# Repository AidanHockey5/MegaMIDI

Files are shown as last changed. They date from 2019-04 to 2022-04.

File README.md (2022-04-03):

# Mega MIDI

https://www.aidanlawrence.com/mega-midi-a-playable-version-of-my-hardware-sega-genesis-synth/

[Instruction Manual](https://www.aidanlawrence.com/wp-content/uploads/2019/07/MegaMidi5Manual.pdf)

[Store Link](https://www.aidanlawrence.com/product/mega-midi-5/)

This project contains the source material for the Mega MIDI, a MIDI-controlled Sega Genesis/Megadrive Synthesizer that uses the genuine sound chips from the console itself. The primary FM sound source is the Yamaha YM2612, but I have also included the SN76489 PSG which was also present on the Sega Genesis. This synthesizer does not use emulated sound - it's the real deal. Therefore, you are limited to the limitations of the actual hardware, which I will explain in more detail down below.

# Why Not Just Emulate?
You'd be hard-pressed to find an emulated YM2612 core that sounds exactly like the real YM2612. There are some that get close, but nothing compares to the real thing. Yamaha's FM synthesis is pretty tricky to emulate in the first place, but the YM2612's signature gritty DAC is mostly to blame for the lack of truly accurate emulation. Not with The Mega MIDI though. Since you are using the real YM2612 and SN76489 ICs, you can experience playing the Sega Genesis as a musical instrument with the true fidelity and accuracy as the real thing.

# Play Any Instrument from Any Genesis Video Game Music
The Mega MIDI reads in ".opm" files. OPM files were originally designed for the VOPM virtual synthesizer. The OPM format stores the register data for FM patches that you can use to easily program your YM2612 with. FM synthesis is very complicated, so while you still have the option to create your own FM patches, it would be way easier to just directly take the FM voice patches from the games themselves and use them on your Mega MIDI. With the Mega MIDI, you can, in fact, DIRECTLY play FM patches from any Sega Genesis game's music. These aren't "sound-alike" patches either, they are the actual identical patches lifted directly from the game's source. Do you like ThunderForce's Guitar patch in the track Metal Squad? Play it. Want to try your hand playing Chemical Plant Zone's bass patch? Go for it. Any track. Any instrument. Instantly.

# Where Do I find OPM files?
There are two ways:

1) There is a massive pack of ripped OPM files ready to go that spans almost the entire Genesis library. You can find just about anything in this collection. [Click here to download it.](https://www.aidanlawrence.com/wp-content/uploads/2019/03/2612org-OPMs.zip)
One thing to note: This is a REALLY big collection of files. I don't recommend putting them ALL on your SD card at once as load times will begin to suffer. 

2) You can convert any OPN2(YM2612) .VGM file to an OPM patch using the vgm2opm tool courtesy of [Shiru](https://shiru.untergrund.net) and https://github.com/vampirefrog/fmtools

I have included a windows-compiled binary of vgm2opm within the [tools](https://github.com/AidanHockey5/MegaMIDI/tree/master/tools) directory of this repository along with a batch-file to automatically execute the tool. To use this tool, simply place your desired .vgm/vgz files within the VGM_IN folder, double-click the CONVERT_VGM_OPM.bat file, then retrieve your OPM patch files in the OPM_OUT folder.

# USB MIDI and Traditional DIN MIDI Compatible
Want to control The Mega MIDI through software like Ableton, FL Studio, or any other DAW? You can! The Mega MIDI will show up like any other MIDI-compatible instrument and is able to receive native USB MIDI commands without any sort of serial bridge. 
Prefer old-school traditional 5-pin DIN MIDI instead? Go for it! Bust out that classic MIDI controller and plug it in with zero additional setup required.

# Crystal-Clear Amplification 
Now featuring a modified version of the Mega Amp Mod! Beautifully clear amplification for both the YM3438 and the YM2612!

# 7 "Favorite" Buttons to Quickly Swap Between Your Favorite Patches
While you do have access to every .opm file on your Mega MIDI's SD card, sometimes you'll find the *perfect* patch that you'll want to keep for easy-access later. Simply hold-down one of the seven "favorite" buttons at the bottom of the board and your currently loaded patch will be saved into EEPROM. Because favorite patches are saved to EEPROM, you can access them instantaneously without any load times. Perfect for swapping patches on-the-fly!

# Real Hardware, Real Limitations
Because you are working with the real sound chips, you are also working under their real limitations. The YM2612 is a six-channel sound chip, meaning you can play six individual notes at once. The SN76489 PSG is a 3-channel square-wave-only (excluding noise) chip. In total, you can have nine total channels of sound if you're playing both the PSG and the YM2612 at the same time.

While some might find this a bit limiting, others may enjoy the challenge of getting as much sound as they possibly can within the limits of the genuine hardware. Countless other video game music composers did it, now you can experience it too!

# Open-source
All of my source material has been made open-source. Want to build your own Mega MIDI from scratch? Go for it! Have some modifications in mind? I'd love to see them! If you do decide your own version, please credit me: Aidan Lawrence and refer back to this original repository. Please do not resell this project.

# Tools
The firmware for this project was developed in [Visual Studio Code](https://code.visualstudio.com/) with the [PlatformIO extention.](https://docs.platformio.org/en/latest/ide/vscode.html) I used the Teensyduino (ArduinoTeensy) toolchain.

The schematics/PCB files were made with [KiCAD.](http://kicad.org/) Specifically, version 5.0.2.

Precompiled firmware HEX files can be found here:
https://github.com/AidanHockey5/MegaMIDI/releases/

Here is the schematic:
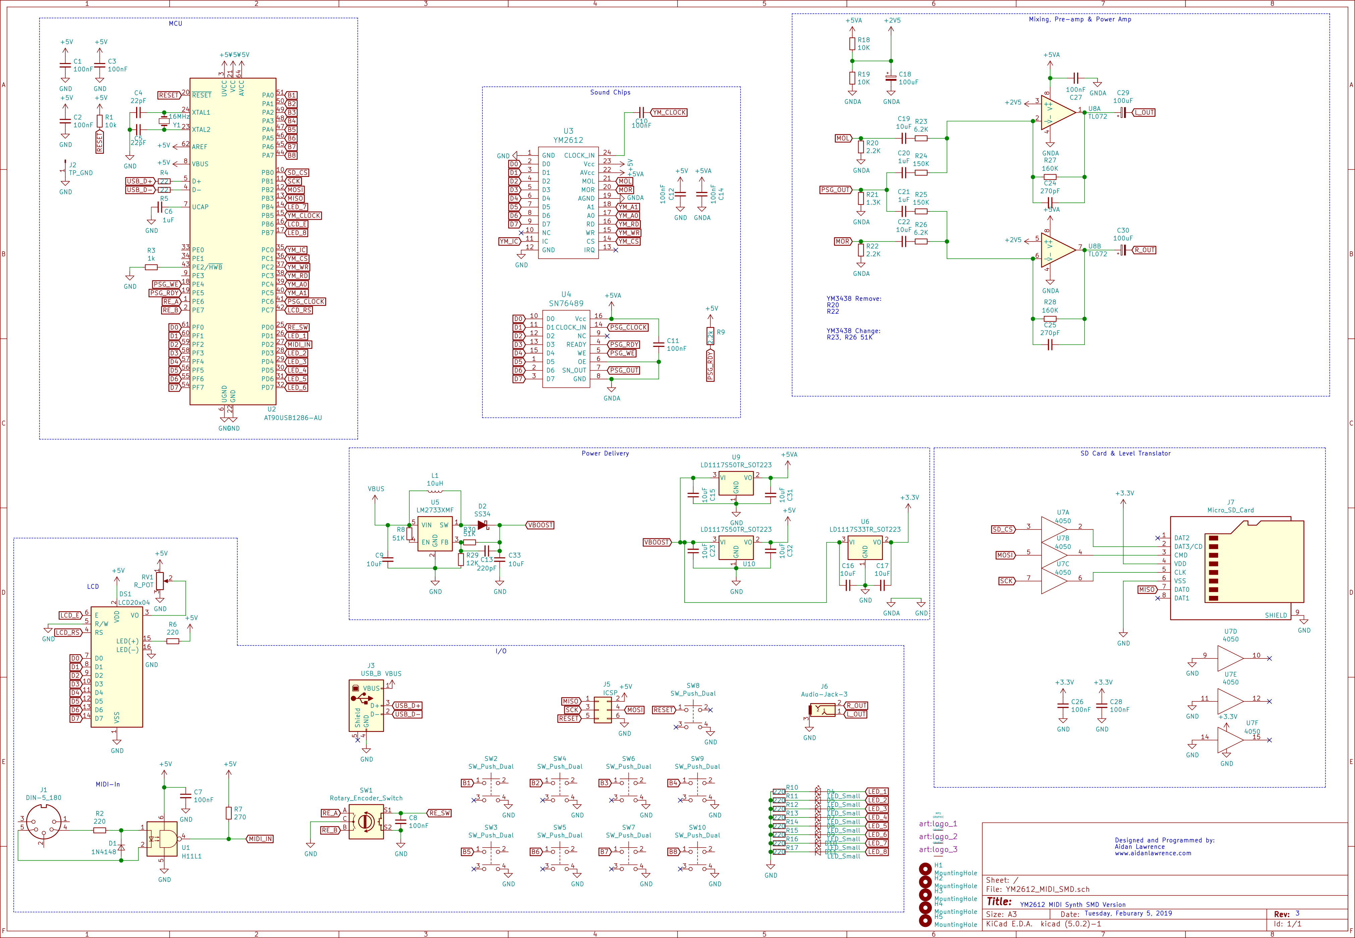
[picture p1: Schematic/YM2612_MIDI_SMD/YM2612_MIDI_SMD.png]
Here is the schematic so far


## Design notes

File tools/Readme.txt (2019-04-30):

Here are a few tools to help you operate the YM2612 MIDI device
You need to make sure you have installed the Teensyduino files from PJRC!
https://www.pjrc.com/teensy/td_download.html

SERIAL CONNECTIONS
--------------------------------------------------
You can use the SERIAL_CONNECT.bat file to open up a virtual serial port in order to send commands to the device.

Inside of the SERIAL_CONNECT.bat file reads:
::This batch file will open the teensy_gateway program and a putty serial window
::Keep the black teensy_gateway window open and work inside of the putty window
::If everything is working, you should see the text "teensy_gateway" inside of the putty window.
::Use the putty window as if you were using the Arduino Serial console.
::Type-in your commands, then hit enter to execute them

CONVERT VGM FILES TO OPM FILES
--------------------------------------------------
You can use this tool to extract the voices out of VGM files and place them in an .OPM file to use with your YM2612 MIDI device
The VGM files MUST contain YM2612/YM3438 instrument data

Place your VGM/VGZ files in the VGM_IN and run the "CONVERT_VGM_OPM.bat" file.
After the program runs, go into the OPM_OUT folder and you should see your new .OPM files.
Add these .OPM files to the SD card of your YM2612 MIDI project.

PROGRAMMING
--------------------------------------------------
While you can easily use something like an ATMEL ICE programmer and Atmel Studio, you can also use a plain ol' Arduino board to act
as a programmer.

You can use the ArduinoISP sketch from the Arduino IDE to turn any standard Arduno Uno/Nano/Mega into a programmer.
It is reccomended that you change the ArduinoISP programmer speed to  #define BAUDRATE	1000000 (line 144), but the default
setting of 19200 works too, though it is very slow.

Pin connections:
The Mega MIDI 6-pin programming connector looks like this:

      MISO °. . 5V 
      SCK   . . MOSI
      RST   . . GND

Arduino | Mega MIDI programming header
GND     | GND
10      | RST
11      | MOSI
12      | MISO
13      | SCK

You do not need to connect 5V.

Run FLASH.bat and choose your COM port number and programming speed.

The SD card will not read properly after being programmed with an ISP device. Remove the SD card, reinsert the card, then press the RESET button on the Mega MIDI board.

Default AVRDUDE command is:
avrdude -c arduino -p usb1286 -P COM16 -b 19200 -U flash:w:"LOCATION_OF_YOUR_PROJECT_FOLDER\.pioenvs\teensy20pp\firmware.hex":a -U lfuse:w:0x5E:m -U hfuse:w:0xDF:m -U efuse:w:0xF3:m

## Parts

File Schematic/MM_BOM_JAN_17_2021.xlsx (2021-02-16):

Quantity | Manufacture Part Number | Manufacturer(optional) | Description(optional) | LCSC Part Number(optional) | Package(optional) | Customer Part Number(optional)
3 | VDV107M035S0ANE04K |  | 100uF | C190423
2 | 0603N220J500CT |  | 22pF | C302059
1 | CL10B221KB8NNNC |  | 220pF | C1603
12 | TCC0805X7R104K500DT |  | 100nF | C282732
3 | CC0805KKX5R6BB105 |  | 1uF | C408907
2 | 0805B271K500CT |  | 270pF | C237202
10 | CL31B106KAHNNNE |  | 10uF | C14860
10 | RMC08052201%N |  | 220R | C325771
3 | 0805W8F1002T5E |  | 10K | C17414
3 | 0805W8F2201T5E |  | 2.2K | C17520
2 | 0805W8F220JT5E |  | 22R | C17561
2 | 0805W8F5102T5E |  | 51K | C17737
2 | 0805W8F6201T5E |  | 6.2K | C17767
2 | WR08X1583FTL |  | 150K | C170801
2 | 0805W8F1603T5E |  | 160K | C17485
1 | WR08X102JTL |  | 1K | C384174
1 | RTT052700FTP |  | 270R | C104166
1 | RK73B2ATTD132J |  | 1.3K | C316774
1 | AECR0805F12K0K9 |  | 12K | C352272
1 | SWPA4018S100MT |  | 10uH | C83442
1 | SS12 |  | SCHOTTKY | C2479
1 | 1N4148W |  | 1N4148 | C84367
8 | TJ-S2012SW8TGLC2R-A5 |  | LED RED | C192318
1 | H11L1SR2M |  | OPTOISOLATOR | C20082
1 | HEF4050BT,653 |  | 4050 BUFFER | C118326
1 | LM833DT |  | OPAMP | C127074
2 | LD1117-5.0 |  | REGULATOR 5V | C347230
1 | LD1117-3.3 |  | REGULATOR 3.3V | C347229
1 | X49SM16MSD2SC |  | 16MHZ CRYSTAL | C12676
1 | 3362P-1-103 |  | POT 10K | C118956
9 | TS-1002-06026 |  | TACT SWITCH | C455093
1 | C124384 |  | PIN HEADER | C124384
1 | DS1009-24AT1WX-0A2 |  | SOCKET DIP24 | C72120
1 | C146580 |  | SOCKET DIP16 | C146580
1 | TF-15x15 |  | SD SOCKET | C111196
1 | LM2733XMFX/NOPB |  | LM2733 | C80169
1 | PJ-307N5 |  | AUDIO JACK | C692542
1 | C46392 |  | USB-B | C46392

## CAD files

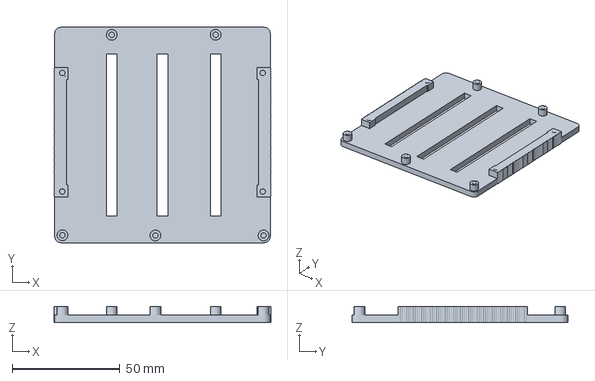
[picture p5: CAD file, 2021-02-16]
3D/Mega_MIDI_Bottom_Plate.3mf
100.7 x 100.0 x 7.55 mm

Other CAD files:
3D/Mega_MIDI_Bottom_Plate.stl

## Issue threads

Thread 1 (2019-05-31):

possible to stick note while receiving midi and pushing encoder

geslotencirkel, 2019-05-31:
when Megamidi is getting midi note data (ch1) it is possible to make notes stick forever.

to reproduce:
-load an opm sound to play.
-send midi notes, preferably fast
-start pushing the encoder to scroll through the onscreen menu

haven't tried this with USB midi, only din.

seems that note off data isn't sent if the encoder is pressed down during a note off event? just a hunch

AidanHockey5, 2019-05-31:
Interesting, I'll give this a look on my unit.
When a new OPM file is loaded in, both of the sound chips are reset. Pushing the encoder will trigger an interrupt routine to update the cursor position and redraw the screen. The interrupt is only triggered on the falling edge of the encoder signal, so I'm curious to see why it's preventing keyOff MIDI commands.

In the meantime if a YM2612 voice is getting stuck on you, pressing the LFO button twice will reset the sound chip.

AidanHockey5, 2019-06-01:
I was able to replicate your issue over serial DIN MIDI, but not using a USB MIDI connection. Since serial operations are interrupt-based, I'm pretty sure the following happened:

I think it has to do with the fact that I was redrawing the LCD inside of the interrupt attached to the rotary encoder's button. Redrawing the LCD takes far too long for a well-performing interrupt, so I've just set a flag instead and will now update the LCD inside of the main loop.

I haven't been able to replicate the stuck voice after I implemented this fix, but since it's an intermittent problem (my favorite... ugh) only time will tell if it's truly fixed. For now though, I'll go ahead and close this issue. Feel free to drop by again if the issue persists!

Here is the pre-compiled hex with the changes made: https://github.com/AidanHockey5/MegaMIDI/releases/tag/1.2.4

Closed 2019-06-01.

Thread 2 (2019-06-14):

Fix for oscillating power amplifier (Output static fix)

AidanHockey5, 2019-06-14:
Hello everyone.

I've noticed a really annoying intermittent hardware bug related to the power amplifier. If you've connected power to your Mega MIDI module and have noticed no "FM sound" and just a bunch of static (or other popping noises), feel your power amplifier IC (U8 on the far right side). If it is getting warm, you are likely experiencing an oscillating amplifier.

*The reason for this is as follows:*
1) The LC filter values are off. C31/32 should be 0.68uF, not 68nF. L3/4 need to be 22uH, not 2.2mH. This is an artifact of my Mega Blaster design that boosted treble, but in this case, it causes instability.
2) My routing in that area is less than ideal. I think the inductors are a little too far away.

*Solutions:*
1) Simply unplug the power supply, wait a moment for the power capacitors to drain, then reapply power. Occasionally, this will work.
2) Replace the components. Unfortunately, this is a little involved. I will give a step-by-step down below on how to replace your components.
3) Tap a 100nF capacitor (rated for at least 16V) against U8's pin 19 and 20. This should give the amp a little capacitive kick to drop out of it's oscillation.
4) Permanently apply 100nF ceramic disc capacitors across U8's pin 11/12 and pin 19/20. This is not recommended as you are essentially shorting the power amplifier. This fix is a "band-aid" and will cause the amp and caps to warm up to around 70°C. You can usually stuff the caps within the IC socket then add the amp chip back over-top. Again, this method is not recommended, but is listed since it's one of the easier fixes.

# Replacing the components
In order to access the necessary components, you will need to remove the display and plastic back plate.

1) Begin by unscrewing the four corner screws on the LCD module.
2) Using a heat-gun or soldering iron, quickly heat as many pins as you can (applying lots fresh solder helps!) and apply a firm upwards pressure to lift the display off of it's pins.
3) You will need to use a solder-pump to remove the excess solder blocking off the LCD pin-holes. You can also use a can of air-duster/compressed air to blast the solder out, but show caution as hot solder may fly everywhere.
4) Remove the five back plate screws and the 4 standoffs, then remove the back plate.
5) Locate L3 and L4. Apply heat to both of their pins and pull from the other side to remove.
6) Remove C32 and C31.
7) Replace C32 and C31 with a 0.68uF 0805 capacitor rated for 16V+
* Here are some! https://www.digikey.com/products/en/capacitors/ceramic-capacitors/60?k=0805%200.68uF
8) Replace L3 and L4 with 22uH radial inductors (8.7x11mm)
* Here are some! https://www.digikey.com/product-detail/en/samsung-electro-mechanics/CL21B684JOFNNNE/1276-2976-1-ND/3891062

Ensure that your LCD header pins sticking out of the main board are clear of any excess solder.

9) Screw the back plate back on using the 5 screws, then screw-in the standoffs. Show caution not to snap-off any of the screws or standoffs by over-torquing them or bending them!
10) Align your LCD onto the standoffs and make sure all of the pins are in their correct location.
11) Re-solder the LCD.

All done!

# What now?

Any Mega MIDIs ordered from me after June 13 2019 will already have this fix applied to them.
A future revision to the Mega MIDI is in the works that will optimize the board layout and hopefully provide better A/D separation. The amplifier circuit will also be replaced with a design based on the Mega Amp Mod. This will simplify my BOM and will make it easier to support YM3438s.

Stay tuned, sorry for the inconvenience! Thank you so much for your patience and support.

Closed 2019-07-01.

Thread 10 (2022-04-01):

Change encoder direction

KeenVox, 2022-04-01:
Hi,

is there a way to change the turning direction of the encoder in software? My encoder seems to decrease when I turn in clockwise instead of increase.

Thx in advance!

AidanHockey5, 2022-04-01:
Hello @KeenVox

Ah, no good. I wonder if you have a bad encoder.
Quick question: Does the encoder _always_ operate in reverse?
As in, counter-clockwise increments and clockwise decrements 100% of the time?
Or is it "most of the time clockwise increments, but sometimes it decrements?"

If it's the former, I should be able to come up with a software patch for your unit.
if it's the latter, I'll follow up and we'll see if we can get this repaired!

-Aidan

KeenVox, 2022-04-02:
Hi Aidan,

thank you for your replay. The encoder always operates in reverse. It works totally fine just the wrong way :-D

A software patch would be great. It's a bit irretating in the moment.

Thx again!

Keen

AidanHockey5, 2022-04-03:
Hey there!

So I've worked on a new feature that allows users to invert their encoder direction by holding down their encoder button for one second. [You can read more about it in the firmware patch notes here.](https://github.com/AidanHockey5/MegaMIDI/releases/tag/1.51)

To update your firmware, you'll need an Arduino and just a couple cheap components. [I've created a flashing guide in the instruction manual on page 11](https://www.aidanlawrence.com/wp-content/uploads/2019/07/MegaMidi5Manual.pdf)

You can also find a video guide here https://www.youtube.com/watch?v=DDNO9py8enI

I know that updating the firmware is a little bit involved, but once it's done, you should be able to invert your encoder and have your unit behave in a more intuitive manner.

I apologize for the inconvenience, but I hope this helps out! Feel free to let me know if you have any questions at all or need assistance flashing the firmware.

KeenVox, 2022-04-03:
Hey, thats great! Thank you!

Closed 2022-04-03.

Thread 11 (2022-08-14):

Pitch bend does not center correctly on the SN76489

wik-wav, 2022-08-14:
After adding a midi automation lane and sending any pitch bend change in a DAW (and I presume moving the pitch wheel would cause this as well, but I can't test this as I have no controller) the pitch of the SN76489 moves down by half of the total pitch bend range. In DAWs where there is always a midi lane, the pitch is wrong from the start. This happens on midi channels 2 and 4.

For example if the note C is played, the note 2 semitones below it is A#. Before adding the pitch bend automation the note C is played. After adding PB, the note A# is played with the pitchbend at 0.

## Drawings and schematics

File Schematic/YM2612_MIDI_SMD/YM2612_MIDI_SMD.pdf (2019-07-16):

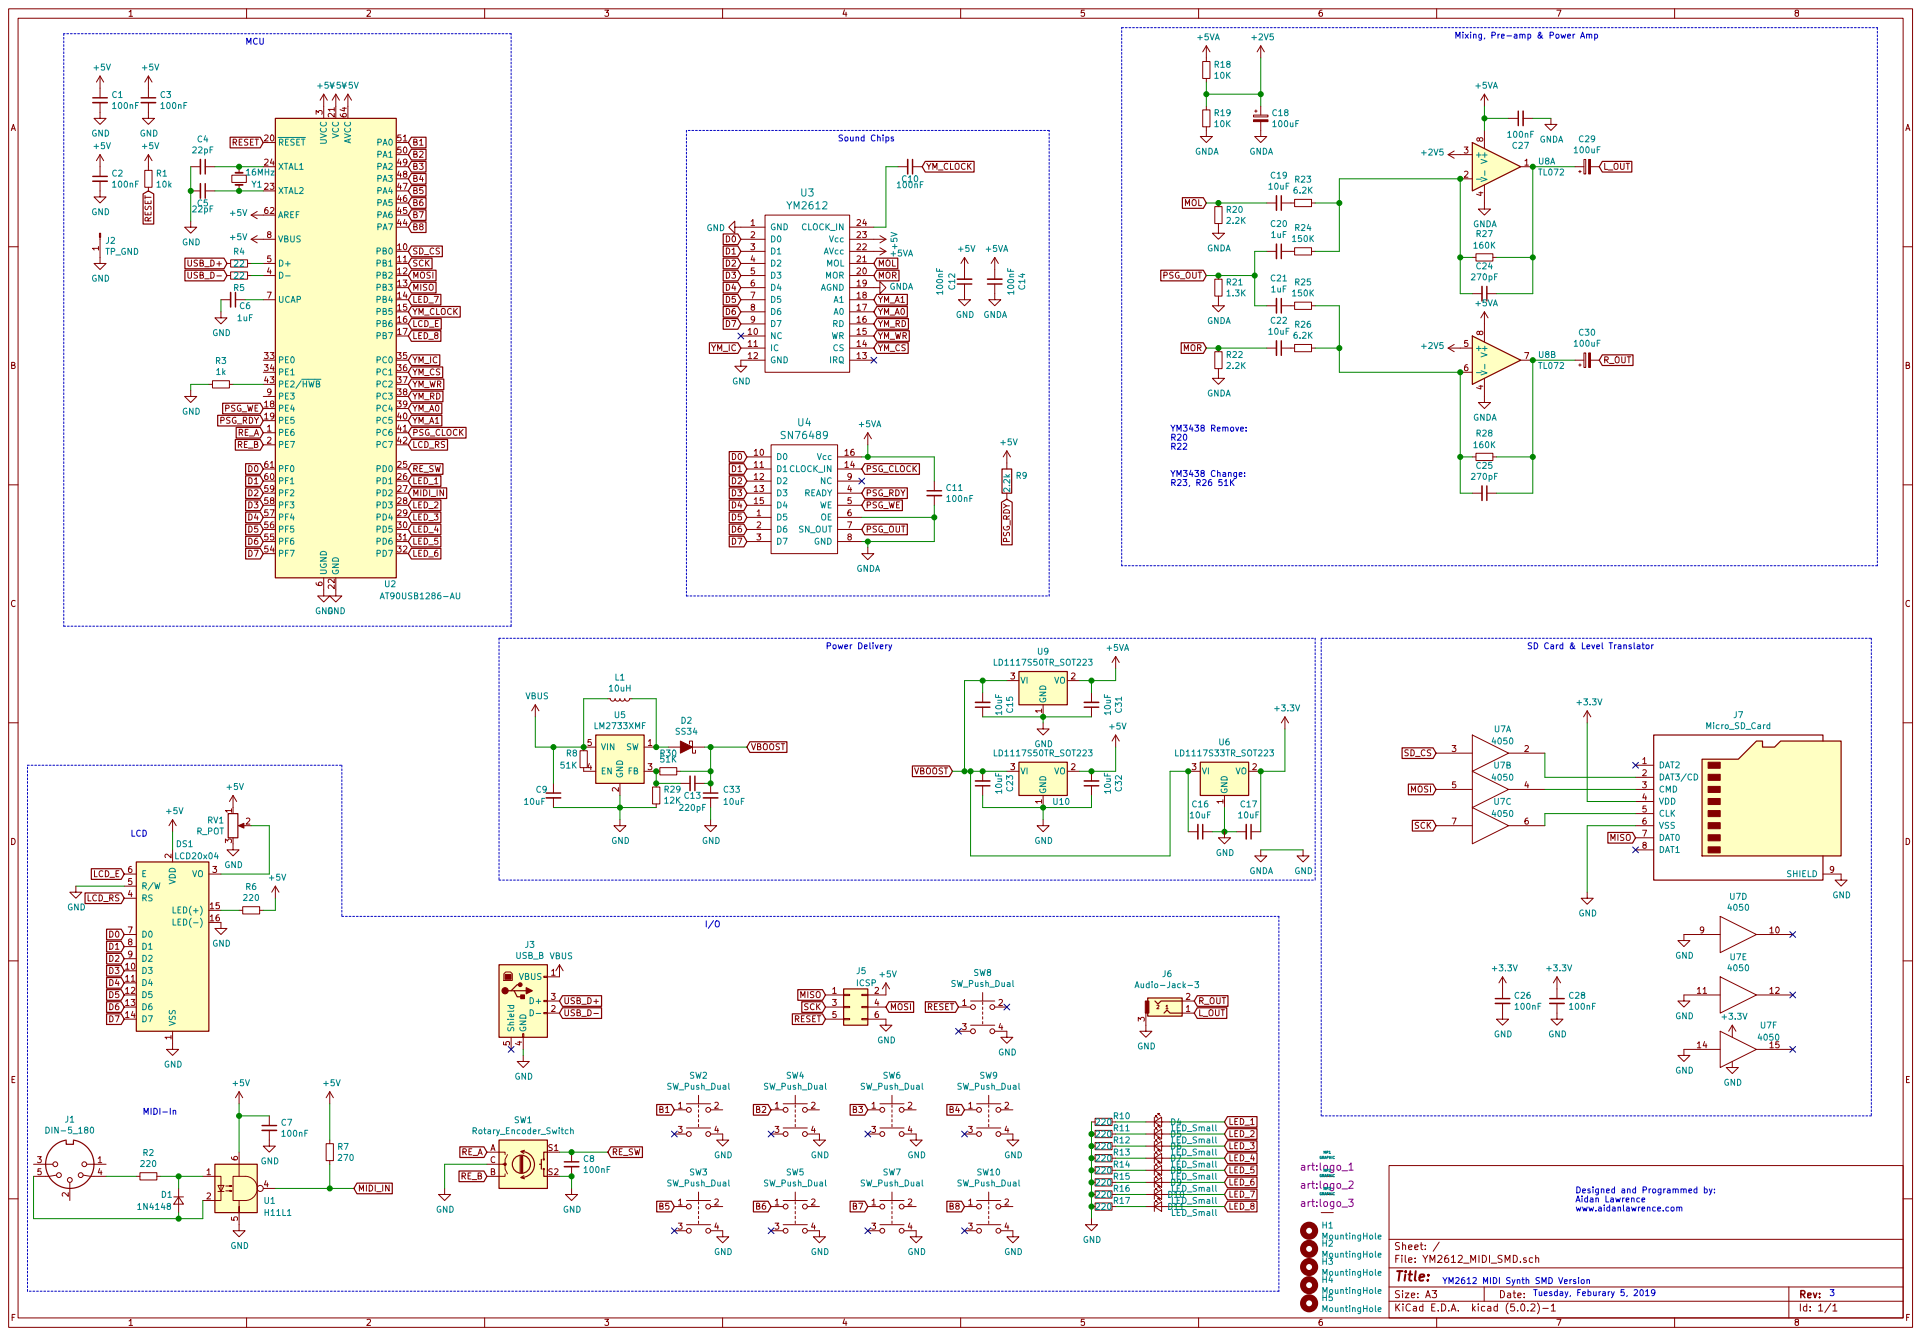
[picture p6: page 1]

Mixing, Pre-amp & Power Amp 3 U8A

MCU

6 PF1 60 PF0 61 AREF 62 AVCC 64 UCAP 7 VBUS 8 PE3 9 U2 AT90USB1286-AU

MP1 GRAPHIC art:logo_1 MP2 GRAPHIC art:logo_2 MP3 GRAPHIC art:logo_3

Designed and Programmed by: Aidan Lawrence www.aidanlawrence.com

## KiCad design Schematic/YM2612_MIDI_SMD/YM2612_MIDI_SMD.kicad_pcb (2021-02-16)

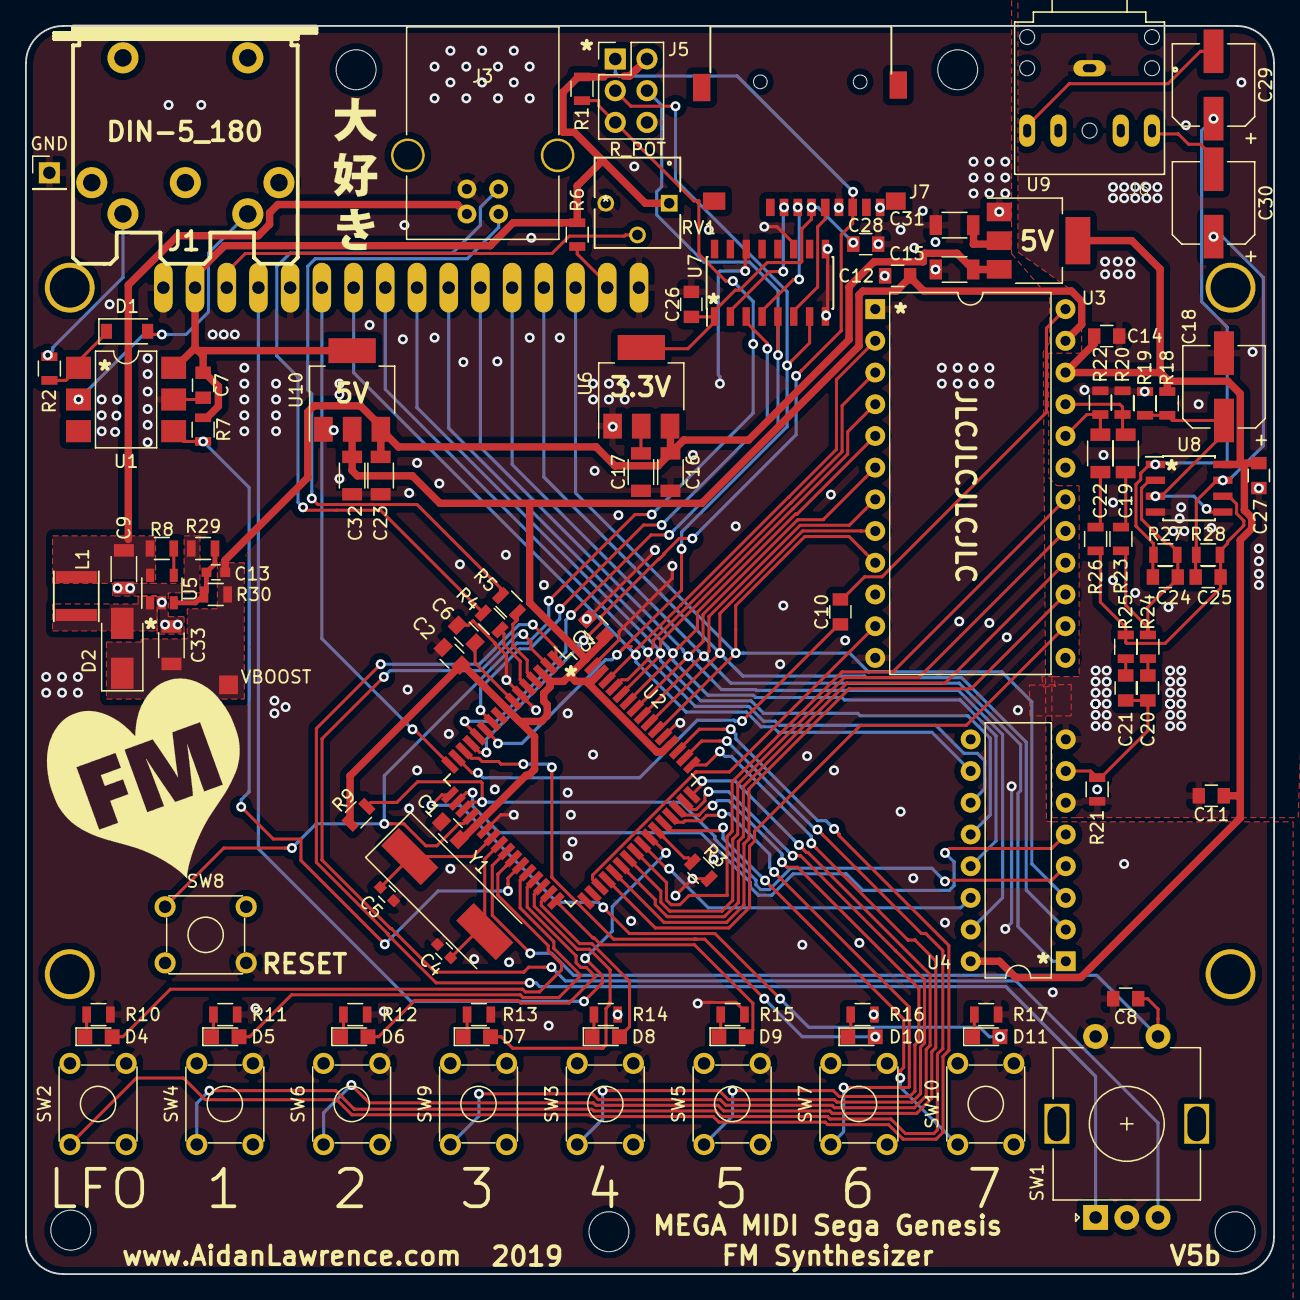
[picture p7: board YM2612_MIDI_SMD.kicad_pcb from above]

Board: 2 copper layers, 100.0 x 100.0 mm, 112 parts (1 on the bottom side), 93 nets.

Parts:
C1, C2, C3, C7, C8, C10, C11, C12, C14, C26, C27, C28: 100nF; C_0805
C4, C5: 22pF; C_0603
C6, C20, C21: 1uF; C_0805
C9, C15, C16, C17, C19, C22, C23, C31, C32, C33: 10uF; C_1206
C13: 220pF; C_0603
C18, C29, C30: 100uF; CP_Elec_6.3x7.7
C24, C25: 270pF; C_0805
D1: 1N4148; D_SOD-123
D2: SS34; D_SMA
D4, D5, D6, D7, D8, D9, D10, D11: LED_Small; LED_0805
DS1: LCD20x04; LCD-20x4
GND: TP_GND; Pin_Header_Straight_1x01_Pitch2.54mm
H1, H2, H3, H4, H5: MountingHole; MountingHole_3.2mm_M3
J1: DIN-5_180; din-5
J3: USB_B
J5: ICSP; Pin_Header_Straight_2x03_Pitch2.54mm
J6: Audio-Jack-3; SWITCHCRAFT_35RAPC4BHN2
J7: Micro_SD_Card; SOFNG_TF_15x15_PUSH_PUSH
L1: 10uH; L_4x4
MP1: GRAPHIC; logo_1
MP2: GRAPHIC; logo_2
MP3: GRAPHIC; logo_3
R1: 10k; R_0805
R2, R6, R10, R11, R12, R13, R14, R15, R16, R17: 220; R_0805
R3: 1k; R_0805
R4, R5: 22; R_0805
R7: 270; R_0805
R8, R30: 51K; R_0805
R9: 2.2k; R_0805
R18, R19: 10K; R_0805
R20, R22: 2.2K; R_0805
R21: 1.3K; R_0805
R23, R26: 6.2K; R_0805
R24, R25: 150K; R_0805
R27, R28: 160K; R_0805
R29: 12K; R_0805
RV1: R_POT; 3362P-1-103LF
SW1: Rotary_Encoder_Switch; RotaryEncoder_Alps_EC11E-Switch_Vertical_H20mm
SW2, SW3, SW4, SW5, SW6, SW7, SW8, SW9, SW10: SW_Push_Dual; SW_TH_Tactile_Omron_B3F-10xx
U1: H11L1; SMDIP-6_W7.62mm
U2: AT90USB1286-AU; TQFP-64_14x14mm_Pitch0.8mm
U3: YM2612; DIP-24_W15.24mm
U4: SN76489; DIP-16_W7.62mm
U5: LM2733XMF; SOT-23-5
U6: LD1117S33TR_SOT223; SOT-223-3_TabPin2
U7: 4050; SOIC-16_3.9x9.9mm_Pitch1.27mm
U8: TL072; SOIC-8_3.9x4.9mm_Pitch1.27mm
U9, U10: LD1117S50TR_SOT223; SOT-223-3_TabPin2
VBOOST: Measurement_Point_Square-SMD-Pad_Small
Y1: 16MHz; Crystal_SMD_HC49-SD

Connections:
+2V5: C18.1, R18.2, R19.1, U8.3, U8.5
+3V3: C17.1, C26.1, C28.1, J7.4, U6.2, U7.1
+5V: C1.1, C2.1, C3.1, C7.1, C12.2, C32.2, DS1.2, J5.2, R1.1, R6.1, R7.1, R9.1, RV1.1, U1.6, U2.3, U2.8, U2.21, U2.52, U2.62, U2.64, U3.23, U10.2
+5VA: C11.1, C14.2, C27.1, C31.2, R18.1, U3.22, U4.16, U8.8, U9.2
B1: SW2.1, U2.51
B2: SW4.1, U2.50
B3: SW6.1, U2.49
B4: SW9.1, U2.48
B5: SW3.1, U2.47
B6: SW5.1, U2.46
B7: SW7.1, U2.45
B8: SW10.1, U2.44
D0: DS1.7, U2.61, U3.2, U4.10
D1: DS1.8, U2.60, U3.3, U4.11
D2: DS1.9, U2.59, U3.4, U4.12
D3: DS1.10, U2.58, U3.5, U4.13
D4: DS1.11, U2.57, U3.6, U4.15
D5: DS1.12, U2.56, U3.7, U4.1
D6: DS1.13, U2.55, U3.8, U4.2
D7: DS1.14, U2.54, U3.9, U4.3
GND: C1.2, C2.2, C3.2, C4.2, C5.2, C6.2, C7.2, C8.2, C9.2, C11.2, C12.1, C14.1, C15.1, C16.1, C17.2, C18.2, C23.1, C26.2, C27.2, C28.2, C31.1, C32.1, C33.2, DS1.1, DS1.5, DS1.16, GND.1, J3.4, J5.6, J6.3, J7.6, J7.9, R3.2, R10.2, R11.2, R12.2, R13.2, R14.2, R15.2, R16.2, R17.2, R19.2, R20.2, R21.2, R22.2, R29.1, RV1.3, SW1.C, SW1.S2, SW2.4, SW3.4, SW4.4, SW5.4, SW6.4, SW7.4, SW8.4, SW9.4, SW10.4, U1.5, U2.6, U2.22, U2.53, U2.63, U3.1, U3.12, U3.19, U4.6, U4.8, U5.2, U6.1, U7.8, U7.9, U7.11, U7.14, U8.4, U9.1, U10.1
LCD_E: DS1.6, U2.16
LCD_RS: DS1.4, U2.42
LED_1: D4.2, U2.26
LED_2: D5.2, U2.28
LED_3: D6.2, U2.29
LED_4: D7.2, U2.30
LED_5: D8.2, U2.31
LED_6: D9.2, U2.32
LED_7: D10.2, U2.14
LED_8: D11.2, U2.17
L_OUT: C29.2, J6.1
MIDI_IN: R7.2, U1.4, U2.27
MISO: J5.1, J7.7, U2.13
MOL: C19.2, R20.1, U3.21
MOR: C22.2, R22.1, U3.20
MOSI: J5.4, U2.12, U7.5
unnamed: C4.1, U2.24, Y1.2
unnamed: C5.1, U2.23, Y1.1
unnamed: C6.1, U2.7
unnamed: C10.2, U3.24
unnamed: C13.2, R29.2, R30.2, U5.3
unnamed: C19.1, R23.2
unnamed: C20.1, R24.2
unnamed: C21.1, R25.2
unnamed: C22.1, R26.2
unnamed: C24.1, C29.1, R27.1, U8.1
unnamed: C24.2, R23.1, R24.1, R27.2, U8.2
unnamed: C25.1, C30.1, R28.1, U8.7
unnamed: C25.2, R25.1, R26.1, R28.2, U8.6
unnamed: D1.1, R2.1, U1.1
unnamed: D1.2, J1.5, U1.2
unnamed: D2.2, L1.1, U5.1
unnamed: D4.1, R10.1
unnamed: D5.1, R11.1
unnamed: D6.1, R12.1
unnamed: D7.1, R13.1
unnamed: D8.1, R14.1
unnamed: D9.1, R15.1
unnamed: D10.1, R16.1
unnamed: D11.1, R17.1
unnamed: DS1.3, RV1.2
unnamed: DS1.15, R6.2
unnamed: J1.4, R2.2
unnamed: J7.2, U7.2
unnamed: J7.3, U7.4
unnamed: J7.5, U7.6
unnamed: R3.1, U2.43
unnamed: R4.1, U2.5
unnamed: R5.1, U2.4
unnamed: R8.2, U5.4
PSG_CLOCK: U2.41, U4.14
PSG_OUT: C20.2, C21.2, R21.1, U4.7
PSG_RDY: R9.2, U2.19, U4.4
PSG_WE: U2.18, U4.5
RESET: J5.5, R1.2, SW8.1, U2.20
RE_A: SW1.A, U2.1
RE_B: SW1.B, U2.2
RE_SW: C8.1, SW1.S1, U2.25
R_OUT: C30.2, J6.2
SCK: J5.3, U2.11, U7.7
SD_CS: U2.10, U7.3
USB_D+: J3.3, R4.2
USB_D-: J3.2, R5.2
VBOOST: C13.1, C15.2, C16.2, C23.2, C33.1, D2.1, R30.1, U6.3, U9.3, U10.3, VBOOST.1
VBUS: C9.1, J3.1, L1.2, R8.1, U5.5
YM_A0: U2.39, U3.17
YM_A1: U2.40, U3.18
YM_CLOCK: C10.1, U2.15
YM_CS: U2.36, U3.14
YM_IC: U2.35, U3.11
YM_RD: U2.38, U3.16
YM_WR: U2.37, U3.15

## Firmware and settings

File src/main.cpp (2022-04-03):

//AT90USB1286 Fuses
//Extended: 0xF3
//HIGH: 0xDF
//LOW: 0x5E

//Use SERIAL_CONNECT.bat file found in the 'tools' folder of this repository.
//----OR----
//Access serial connection using Arduino IDE. Ensure that teensy software suite has been installed https://www.pjrc.com/teensy/td_download.html
//In Arduino, look for Tools->Port->(Emulated Serial)
//Open serial monitor
//Device should reset. You may need to try this a couple times.

//Programming:
/*
You can use the ArduinoISP sketch from the Arduino IDE to turn any standard Arduno Uno/Nano/Mega into a programmer.
It is reccomended that you change the ArduinoISP programmer speed to  #define BAUDRATE	1000000 (line 144), but the default
setting of 19200 works too, though it is very slow.

Pin connections:

The Mega MIDI 6-pin programming connector looks like this:

      MISO °. . 5V 
      SCK   . . MOSI
      RST   . . GND

Arduino | Mega MIDI programming header
GND     | GND
10      | RST
11      | MOSI
12      | MISO
13      | SCK

You do not need to connect 5V.

Using the FLASH.bat file found in the tools folder, or by using the terminal below, you can easily flash your Mega MIDI
Vscode terminal command:
////////////////////////
cd tools
./FLASH.bat
///////////////////////

The SD card will not read properly after being programmed with an ISP device. Remove the SD card, reinsert the card, then press the RESET button on the Mega MIDI board.

Default AVRDUDE command is:
avrdude -c arduino -p usb1286 -P COM16 -b 19200 -U flash:w:"LOCATION_OF_YOUR_PROJECT_FOLDER\.pioenvs\teensy20pp\firmware.hex":a -U lfuse:w:0x5E:m -U hfuse:w:0xDF:m -U efuse:w:0xF3:m 
*/

#define FW_VERSION "1.51"



#define F_CPU 16000000UL
#include <SPI.h>
#include "usb_midi_serial.h"
#include <Arduino.h>
#include "Voice.h"
#include "YM2612.h"
#include "SN76489.h"
#include "SdFat.h"
#include <MIDI.h>
#include <Encoder.h>
#include <LiquidCrystal.h>
#include <EEPROM.h>
#include "LCDChars.h"
#include "NPRM.h"

//Music
#include "Adjustments.h" //Look in this file for tuning & pitchbend settings

//MIDI
#define YM_CHANNEL 1
#define PSG_CHANNEL 2
#define YM_VELOCITY_CHANNEL 3
#define PSG_VELOCITY_CHANNEL 4
#define PSG_NOISE_CHANNEL 5

#define YM_VST_ALL 10
#define YM_VST_1 11
#define YM_VST_2 12
#define YM_VST_3 13
#define YM_VST_4 14
#define YM_VST_5 15
#define YM_VST_6 16
uint8_t sendPatchToVST = 0xFF;

NPRM nprm;

MIDI_CREATE_INSTANCE(HardwareSerial, Serial1, MIDI);

//DEBUG
#define DLED 8

//INPUT
#define PROG_UP 5
#define PROG_DOWN 6
#define LFO_TOG 7
#define ENC_BTN 0
Encoder encoder(18, 19);
long encoderPos = 0;
bool isEncoderInverted = false;
uint16_t encoderHoldCount = 0;
uint32_t encoderInvertEEPROMLocation = sizeof(FavoriteVoice)*7+1;

//LCD
#define LCD_ROWS 4
#define LCD_COLS 20
uint16_t fileNameScrollIndex = 0;
uint8_t lcdSelectionIndex = 0;
LiquidCrystal lcd(17, 26, 38, 39, 40, 41, 42, 43, 44, 45); //PC7 & PB6 + Same data bus as sound chips
bool redrawLCDOnNextLoop = false;
bool stopLCDFileUpdate = false;

//Clocks
uint32_t masterClockFrequency = 8000000;

//Sound Chips
SN76489 sn76489 = SN76489();
YM2612 ym2612 = YM2612();
#define PSG_READY 37

//SD Card
SdFat SD;
File file;
#define SD_CHIP_SELECT SS //PB0 
#define FIRST_FILE 0x00
#define NEXT_FILE 0x01
#define PREV_FILE 0x02
#define MAX_FILE_NAME_SIZE 128
char fileName[MAX_FILE_NAME_SIZE];
uint32_t numberOfFiles = 0;
uint32_t currentFileNumber = 0;
bool isFileValid = false;

//Favorites
uint8_t currentFavorite = 0xFF; //If favorite = 0xFF, go back to SD card voices

//Prototypes
void KeyOn(byte channel, byte key, byte velocity);
void KeyOff(byte channel, byte key, byte velocity);
void ProgramChange(byte channel, byte program);
void PitchChange(byte channel, int pitch);
void ControlChange(byte channel, byte control, byte value);
void SystemExclusive(byte *data, uint16_t length);
void HandleFavoriteButtons(byte portValue);
bool LoadFile(byte strategy);
void BlinkLED(byte led);
void ClearLCDLine(byte line);
bool LoadFile(String req);
void PutFavoriteIntoEEPROM(Voice v, uint16_t index);
void SetVoice(Voice v);
void removeMeta();
void ReadVoiceData();
void HandleSerialIn();
void DumpVoiceData(Voice v);
void ResetSoundChips();
void HandleRotaryButton();
void HandleRotaryEncoder();
void LCDRedraw(uint8_t graphicCursorPos = 0);
void ScrollFileNameLCD();
void IntroLEDs();
void UpdateLEDs();
void ProgramNewFavorite();
void SDReadFailure();
void HandleNPRM(uint8_t channel);
void SendPatchSysex(uint8_t slot);
void VSTMode();
Voice GetFavoriteFromEEPROM(uint16_t index);

void setup() 
{
  //YM2612 and PSG Clock Generation
  pinMode(25, OUTPUT);
  pinMode(16, OUTPUT);
  //8MHz on PB5 (YM2612)
  // set up Timer 1
  TCCR1A = bit (COM1A0);  // toggle OC1A on Compare Match
  TCCR1B = bit (WGM12) | bit (CS10);   // CTC, no prescaling
  OCR1A =  0; //Divide by 2

  //4MHz on PC6 (PSG)
  // set up Timer 3
  TCCR3A = bit (COM3A0);  // toggle OC3A on Compare Match
  TCCR3B = bit (WGM32) | bit (CS30);   // CTC, no prescaling
  OCR3A =  1; //Divide by 4

  Serial.begin(115200);
  lcd.createChar(0, arrowCharLeft);
  lcd.createChar(1, arrowCharRight);
  lcd.createChar(2, heartChar);
  lcd.createChar(3, arrowCharInvertedRight);
  lcd.begin(LCD_COLS, LCD_ROWS);

  lcd.print("     Welcome To");
  lcd.setCursor(0,1);
  lcd.print("      MEGA MIDI");
  lcd.setCursor(0,2);
  lcd.print("   Aidan Lawrence");
  lcd.setCursor(0,3);
  lcd.print("        2019  ");
  lcd.print(FW_VERSION);

  MIDI.begin(MIDI_CHANNEL_OMNI);

  delay(20); //Wait for clocks to start
  sn76489.Reset();
  ym2612.Reset();

  usbMIDI.setHandleNoteOn(KeyOn);
  usbMIDI.setHandleNoteOff(KeyOff);
  usbMIDI.setHandleProgramChange(ProgramChange);
  usbMIDI.setHandlePitchChange(PitchChange);
  usbMIDI.setHandleControlChange(ControlChange);
  usbMIDI.setHandleSystemExclusive(SystemExclusive);

  MIDI.setHandleNoteOn(KeyOn);
  MIDI.setHandleNoteOff(KeyOff);
  MIDI.setHandleProgramChange(ProgramChange);
  MIDI.setHandlePitchBend(PitchChange);
  MIDI.setHandleControlChange(ControlChange);

  pinMode(DLED, OUTPUT);
  pinMode(PROG_UP, INPUT_PULLUP);
  pinMode(PROG_DOWN, INPUT_PULLUP);
  pinMode(LFO_TOG, INPUT_PULLUP);
  pinMode(ENC_BTN, INPUT_PULLUP);
  pinMode(PSG_READY, INPUT);

  MIDI.turnThruOff();
  UCSR1B &= ~(1UL << 3); //Release the Hardware Serial1 TX pin from USART transmitter.

  DDRA = 0x00;
  PORTA = 0xFF;
  for(int i = 0; i<8; i++)
  {
    pinMode(leds[i], OUTPUT);
    digitalWrite(leds[i], LOW);
  }
  IntroLEDs();

  if(!SD.begin(SD_CHIP_SELECT, SPI_HALF_SPEED))
  {
    Serial.println("SD Mount failed!");
    SDReadFailure();
  }
  removeMeta();
  attachInterrupt(digitalPinToInterrupt(ENC_BTN), HandleRotaryButton, RISING);
  LoadFile(FIRST_FILE);
  ReadVoiceData();
  if(EEPROM.read(encoderInvertEEPROMLocation) == 0xFF) //eeprom not initialized
    EEPROM.put(encoderInvertEEPROMLocation, 0x00);
  EEPROM.get(encoderInvertEEPROMLocation, isEncoderInverted);
  //ym2612.SetVoice(voices[0]);
  for(uint8_t i = 0; i<MAX_CHANNELS_YM; i++)
      ym2612.SetVoiceManual(i, voices[0]);
  DumpVoiceData(voices[0]);
  LCDRedraw();
}

void PutFavoriteIntoEEPROM(Voice v, uint16_t index)
{
  if(index > 7)
    return;
  FavoriteVoice fv;
  fv.v = v;
  fv.index = index;
  strncpy(fv.fileName, fileName, 20);
  fv.fileName[20] = '\0';
  fv.voiceNumber = currentProgram;
  fv.octaveShift = ym2612.GetOctaveShift();
  EEPROM.put(sizeof(FavoriteVoice)*index, fv);
}

Voice GetFavoriteFromEEPROM(uint16_t index)
{
  if(index >= 8)
    return voices[currentProgram];
  FavoriteVoice fv;
  EEPROM.get(sizeof(FavoriteVoice)*index, fv);
  if(fv.index != index)
  {
    Serial.println("ERROR, index mismatch!");
    Serial.print("Wanted: "); Serial.println(index, HEX);
    Serial.print("Got: "); Serial.println(fv.index, HEX);
    currentFavorite = 0xFF;
    LCDRedraw(lcdSelectionIndex);
    lcd.setCursor(0, 2);
    lcd.print("No favorite set");
    lcd.setCursor(0,3);
    lcd.print("Hold to set favorite");
    return voices[currentProgram];
  }
  ym2612.SetOctaveShift(fv.octaveShift);
  LCDRedraw(lcdSelectionIndex);
  return fv.v;
}

void IntroLEDs()
{
  int i = 0;
  for(i=0; i<8; i++)
  {
    digitalWrite(leds[i], HIGH);
    delay(100);
  }

  for(i=0; i<8; i++)
  {
    digitalWrite(leds[i], LOW);
    delay(100);
  }
}

bool LoadFile(byte strategy) //Request a file with NEXT, PREV, FIRST commands
{
  File nextFile;
  memset(fileName, 0x00, MAX_FILE_NAME_SIZE);
  switch(strategy)
  {
    case FIRST_FILE:
    {
      File countFile;
      while ( countFile.openNext( SD.vwd(), O_READ ))
      {
        countFile.close();
        numberOfFiles++;
      }
      countFile.close();
      SD.vwd()->rewind();

      if(file.isOpen())
        file.close();
      file.openNext(SD.vwd(), O_READ);
      if(!file)
      {
        Serial.println("File Read failed!");
        SDReadFailure();
      }
      file.getName(fileName, MAX_FILE_NAME_SIZE);
      Serial.println(fileName);
      currentFileNumber = 0;
      return true;
    break;
    }
    case NEXT_FILE:
    {
      if(currentFileNumber+1 >= numberOfFiles)
      {
          SD.vwd()->rewind();
          currentFileNumber = 0;
      }
      else
          currentFileNumber++;
      nextFile.openNext(SD.vwd(), O_READ);
      nextFile.getName(fileName, MAX_FILE_NAME_SIZE);
      nextFile.close();
      break;
    }
    case PREV_FILE:
    {
      if(currentFileNumber != 0)
      {
        currentFileNumber--;
        SD.vwd()->rewind();
        for(uint32_t i = 0; i<=currentFileNumber; i++)
        {
          nextFile.close();
          nextFile.openNext(SD.vwd(), O_READ);
        }
        nextFile.getName(fileName, MAX_FILE_NAME_SIZE);
        nextFile.close();
      }
      else
      {
        currentFileNumber = numberOfFiles-1;
        SD.vwd()->rewind();
        for(uint32_t i = 0; i<=currentFileNumber; i++)
        {
          nextFile.close();
          nextFile.openNext(SD.vwd(), O_READ);
        }
        nextFile.getName(fileName, MAX_FILE_NAME_SIZE);
        nextFile.close();
      }
      break;
    }
  }
  if(file.isOpen())
    file.close();
  file = SD.open(fileName, FILE_READ);
  if(!file)
  {
    Serial.println("Failed to read file");
    SDReadFailure();
  }
  ReadVoiceData();
  //ym2612.SetVoice(voices[0]);
  for(uint8_t i = 0; i<MAX_CHANNELS_YM; i++)
    ym2612.SetVoiceManual(i, voices[0]);
  currentProgram = 0;
  fileNameScrollIndex = 0;  // Reset fileName scroll
  LCDRedraw();
  return true;
}

void SDReadFailure()
{
  lcd.clear();
  lcd.home();
  lcd.print("SD card");
  lcd.setCursor(0,1);
  lcd.print("read failure!");
  for(int i = 0; i<8; i++)
  {
    if(i%2==0)
      digitalWrite(leds[i], HIGH);
    else
      digitalWrite(leds[i], LOW);
  }
  while(true){}
}

bool LoadFile(String req) //Request a file (string) to load
{
  bool fileFound = false;
  char searchFn[MAX_FILE_NAME_SIZE];
  SD.vwd()->rewind();
  Serial.print("REQUEST: "); Serial.println(req);
  File nextFile;
  for(uint32_t i = 0; i<numberOfFiles; i++)
  {
    nextFile.close();
    nextFile.openNext(SD.vwd(), O_READ);
    nextFile.getName(searchFn, MAX_FILE_NAME_SIZE);
    String tmpFN = String(searchFn);
    tmpFN.trim();
    req.trim();
    if(tmpFN == req)
    {
      currentFileNumber = i;
      fileFound = true;
      break;
    }
  }
  nextFile.close();
  if(!fileFound)
  {
    Serial.println("Error: File not found!");
    return false;
  }
  memset(fileName, 0x00, MAX_FILE_NAME_SIZE);
  strncpy(fileName, searchFn, MAX_FILE_NAME_SIZE);
  if(file.isOpen())
    file.close();
  file = SD.open(fileName, FILE_READ);
  if(!file)
  {
    Serial.println("Failed to read file");
    digitalWrite(DLED, HIGH);
    while(true){}
  }
  ReadVoiceData();
  //ym2612.SetVoice(voices[0]);
  for(uint8_t i = 0; i<MAX_CHANNELS_YM; i++)
    ym2612.SetVoiceManual(i, voices[0]);
  currentProgram = 0;
  fileNameScrollIndex = 0;  // Reset fileName scroll
  LCDRedraw();
  return true;
}

void removeMeta() //Remove useless meta files
{
  File tmpFile;
  while ( tmpFile.openNext( SD.vwd(), O_READ ))
  {
    memset(fileName, 0x00, MAX_FILE_NAME_SIZE);
    tmpFile.getName(fileName, MAX_FILE_NAME_SIZE);
    if(fileName[0]=='.')
    {
      if(!SD.remove(fileName))
      if(!tmpFile.rmRfStar())
      {
        Serial.print("FAILED TO DELETE META FILE"); Serial.println(fileName);
      }
    }
    if(String(fileName) == "System Volume Information")
    {
      if(!tmpFile.rmRfStar())
        Serial.println("FAILED TO REMOVE SVI");
    }
    tmpFile.close();
  }
  tmpFile.close();
  SD.vwd()->rewind();
}

void HandleRotaryButton()
{
  if(encoderHoldCount >= 1000)
    return;
  lcdSelectionIndex++;
  lcdSelectionIndex %= 3;
  redrawLCDOnNextLoop = true;
}

void LCDRedraw(uint8_t graphicCursorPos)
{
  lcd.clear();
  lcd.home();
  lcdSelectionIndex = graphicCursorPos;
  lcd.setCursor(0, lcdSelectionIndex);
  lcd.print(" ");
  if(lcdSelectionIndex < 2)
  {
    lcd.setCursor(0, lcdSelectionIndex);
    lcd.print(" ");
    lcd.setCursor(0, lcdSelectionIndex);
    isEncoderInverted == true ? lcd.write((uint8_t)3) : lcd.write((uint8_t)0);
  }

  lcd.setCursor(1, 0);
  String fn = fileName;
  fn = fn.remove(LCD_COLS-1);
  lcd.print(fn);
  lcd.setCursor(1, 1);
  if(isFileValid)
  {
    lcd.print("Voice #");
    lcd.print(currentProgram);
    lcd.print("/");
    lcd.print(maxValidVoices-1);
    lcd.print("  ");
  }
  else
  {
    lcd.print("NO VOICES");
  }
  

  lcd.setCursor(15, 1);
  lcd.print("OCT");
  int8_t oct = ym2612.GetOctaveShift();
  if(oct >= 0)
    lcd.print("+");
  lcd.print(oct);
  if(lcdSelectionIndex == 2)
  {
    lcd.setCursor(14, 1);
    lcd.print(" ");
    lcd.setCursor(14, 1);
    isEncoderInverted == true ? lcd.write((uint8_t)3) : lcd.write((uint8_t)0); //Arrow Right
  }

  if(currentFavorite != 0xFF && currentFavorite < 8)
  {
    FavoriteVoice fv;
    EEPROM.get(sizeof(FavoriteVoice)*currentFavorite, fv);
    lcd.setCursor(0, 2);
    lcd.print(fv.fileName);
    lcd.setCursor(0, 3);
    lcd.print("Voice #"); lcd.print(fv.voiceNumber); lcd.print("   "); lcd.write(2); lcd.print(currentFavorite);
  }
}

void ResetSoundChips()
{
  ym2612.Reset();
  sn76489.Reset();
  //ym2612.SetVoice(voices[currentProgram]);
  for(uint8_t i = 0; i<MAX_CHANNELS_YM; i++)
    ym2612.SetVoiceManual(i, voices[currentProgram]);
  Serial.println("Soundchips Reset");
}

void ReadVoiceData()
{
  size_t n;
  uint8_t voiceCount = 0;
  char * pEnd;
  uint8_t vDataRaw[6][11];
  const size_t LINE_DIM = 60;
  char line[LINE_DIM];
  bool foundNoName = false;
  while ((n = file.fgets(line, sizeof(line))) > 0) 
  {
      String l = line;
      //Ignore comments
      if(l.startsWith("//"))
        continue;
      //Ignore voices with no instrument name
      if(l.startsWith("@:"+String(voiceCount)+" no Name"))
      {
        maxValidVoices = voiceCount;
        foundNoName = true;
        break;
      }
      else if(l.startsWith("@:"+String(voiceCount)))
      {
        for(int i=0; i<6; i++)
        {
          file.fgets(line, sizeof(line));
          l = line;
          l.replace("LFO: ", "");
          l.replace("CH: ", "");
          l.replace("M1: ", "");
          l.replace("C1: ", "");
          l.replace("M2: ", "");
          l.replace("C2: ", "");
          l.toCharArray(line, sizeof(line), 0);

          vDataRaw[i][0] = strtoul(line, &pEnd, 10); 
          for(int j = 1; j<11; j++)
          {
            vDataRaw[i][j] = strtoul(pEnd, &pEnd, 10);
          }
        }

        for(int i=0; i<5; i++) //LFO
          voices[voiceCount].LFO[i] = vDataRaw[0][i];
        for(int i=0; i<7; i++) //CH
          voices[voiceCount].CH[i] = vDataRaw[1][i];
        for(int i=0; i<11; i++) //M1
          voices[voiceCount].M1[i] = vDataRaw[2][i];
        for(int i=0; i<11; i++) //C1
          voices[voiceCount].C1[i] = vDataRaw[3][i];
        for(int i=0; i<11; i++) //M2
          voices[voiceCount].M2[i] = vDataRaw[4][i];
        for(int i=0; i<11; i++) //C2
          voices[voiceCount].C2[i] = vDataRaw[5][i];
        voiceCount++;
      }
      if(voiceCount == MAX_VOICES)
        break;
  }
  if(!foundNoName)
    maxValidVoices = voiceCount;
  if(voiceCount == 0)
  {
    isFileValid = false;
    Serial.println("No voices found");
  }
  else
  {
    isFileValid = true;
    Serial.println("Done Reading Voice Data");
  }
}

void DumpVoiceData(Voice v) //Used to check operator settings from loaded OPM file
{
  Serial.print("LFO: ");
  for(int i = 0; i<5; i++)
  {
    Serial.print(v.LFO[i]); Serial.print(" ");
  }
  Serial.println();
  Serial.print("CH: ");
  for(int i = 0; i<7; i++)
  {
    Serial.print(v.CH[i]); Serial.print(" ");
  }
  Serial.println();
  Serial.print("M1: ");
  for(int i = 0; i<11; i++)
  {
    Serial.print(v.M1[i]); Serial.print(" ");
  }
  Serial.println();
  Serial.print("C1: ");
  for(int i = 0; i<11; i++)
  {
    Serial.print(v.C1[i]); Serial.print(" ");
  }
  Serial.println();
  Serial.print("M2: ");
  for(int i = 0; i<11; i++)
  {
    Serial.print(v.M2[i]); Serial.print(" ");
  }
  Serial.println();
  Serial.print("C2: ");
  for(int i = 0; i<11; i++)
  {
    Serial.print(v.C2[i]); Serial.print(" ");
  }
  Serial.println();
}

void PitchChange(byte channel, int pitch)
{
  if(channel == YM_CHANNEL || channel == YM_VELOCITY_CHANNEL || channel == YM_VST_ALL)
  {
    pitchBendYM = pitch;
    for(int i = 0; i<MAX_CHANNELS_YM; i++)
    {
      ym2612.AdjustPitch(i, pitch);
    }
  }
  // else if(channel > YM_VST_ALL && channel <= YM_VST_6)
  // {
  //   pitchBendYM = pitch;
  //   ym2612.AdjustPitch(channel-11, pitch);
  // }
  else if(channel == PSG_CHANNEL || channel == PSG_VELOCITY_CHANNEL)
  {
    for(int i = 0; i<MAX_CHANNELS_PSG; i++)
    {
      sn76489.PitchChange(i, pitch);
    }
  }
}

bool ymVelocityEnabledFlag = false;
void KeyOn(byte channel, byte key, byte velocity)
{
  stopLCDFileUpdate = true;
  if(channel == YM_CHANNEL || channel == YM_VELOCITY_CHANNEL)
  {
    if(isFileValid || currentFavorite != 0xFF)
    {
      if(channel == YM_VELOCITY_CHANNEL)
        ymVelocityEnabledFlag = true;
      else if(ymVelocityEnabledFlag)
      {
        ymVelocityEnabledFlag = false;
        for(uint8_t i = 0; i<MAX_CHANNELS_YM; i++)
          ym2612.SetVoiceManual(i, voices[currentProgram]);
        //ym2612.SetVoice(voices[currentProgram]);
      }
      ym2612.SetChannelOn(key+SEMITONE_ADJ_YM, velocity, ymVelocityEnabledFlag);
    }
  }
  else if(channel == PSG_CHANNEL || channel == PSG_VELOCITY_CHANNEL)
  {
    sn76489.SetChannelOn(key+SEMITONE_ADJ_PSG, velocity, channel == PSG_VELOCITY_CHANNEL);
  }
  else if(channel == PSG_NOISE_CHANNEL)
  {
    sn76489.SetNoiseOn(key, velocity, 1);
  }
}

void KeyOff(byte channel, byte key, byte velocity)
{
  if(channel == YM_CHANNEL || channel == YM_VELOCITY_CHANNEL)
  {
    ym2612.SetChannelOff(key+SEMITONE_ADJ_YM);
  }
  else if(channel == PSG_CHANNEL || channel == PSG_VELOCITY_CHANNEL)
  {
    sn76489.SetChannelOff(key+SEMITONE_ADJ_PSG);
  }
  else if(channel == PSG_NOISE_CHANNEL)
  {
    sn76489.SetNoiseOff(key);
  }
}

void ControlChange(byte channel, byte control, byte value)
{
  //Serial.print("CONTROL: "); Serial.print("CH:"); Serial.print(channel); Serial.print("CNT:"); Serial.print(control); Serial.print("VALUE:"); Serial.println(value);
  if(control == 0x01 && (channel == YM_CHANNEL || channel == YM_VELOCITY_CHANNEL))
  {
    ym2612.AdjustLFO(value);
  }
  else if(control == 0x01 && channel == PSG_NOISE_CHANNEL)
  {
    sn76489.MIDISetNoiseControl(0x01, value);
  }
  else if(control == 0x40) //Sustain
  {
    if(channel == YM_CHANNEL || channel == YM_VELOCITY_CHANNEL)
    {
      YMsustainEnabled = (value >= 64);
      YMsustainEnabled == true ? ym2612.ClampSustainedKeys() : ym2612.ReleaseSustainedKeys();
    }
    else if(channel == PSG_CHANNEL || channel == PSG_VELOCITY_CHANNEL)
    {
      PSGsustainEnabled = (value >= 64);
      PSGsustainEnabled == true ? sn76489.ClampSustainedKeys() : sn76489.ReleaseSustainedKeys();
    }
  }
  else
  {
    switch (control) //NRPN to control synth manually
    {
      case 99:
      nprm.parameter = value << 7;
      break;
      case 98:
      nprm.parameter += value;
      break;
      case 6:
      nprm.value = value << 7;
      break;
      case 38:
      nprm.value = nprm.value + value;

      //Handle NPRM
      //Serial.print("NPRM --- "); Serial.print("PARAM: "); Serial.print(nprm.parameter); Serial.print("   "); Serial.print("VALUE: "); Serial.println(nprm.value);

      HandleNPRM(channel);
      break;
      default:
      return;
    }
  }
}
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
void loop() 
{
  while (usbMIDI.read()) {};
  MIDI.read();
  HandleRotaryEncoder();
  if(redrawLCDOnNextLoop)
  {
    redrawLCDOnNextLoop = false;
    LCDRedraw(lcdSelectionIndex);
  }
  ScrollFileNameLCD();
  
  if(Serial.available() > 0)
    HandleSerialIn();
  byte portARead = ~PINA;
  if(portARead)
    HandleFavoriteButtons(portARead);
  if(sendPatchToVST != 0xFF)
  {
    SendPatchSysex(sendPatchToVST);
    sendPatchToVST = 0xFF;
  }
  while(!digitalReadFast(ENC_BTN) && encoderHoldCount < 1000)
  {
    delay(1);
    encoderHoldCount++;
    if(encoderHoldCount == 1000)
    {
      isEncoderInverted ^= true; //toggle
      isEncoderInverted == true ? Serial.println("Inverted Encoder...") : Serial.println("Normalized Encoder...");
      EEPROM.put(encoderInvertEEPROMLocation, isEncoderInverted);
      LCDRedraw(lcdSelectionIndex);
      break;
    }
  }
  if(digitalReadFast(ENC_BTN))
    encoderHoldCount = 0;
}
 

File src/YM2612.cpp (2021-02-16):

#include "YM2612.h"


YM2612::YM2612()
{
    DDRF = 0xFF;
    PORTF = 0x00;
    DDRC = 0xFF;
    PORTC |= 0x3C; //_A1 LOW, _A0 LOW, _IC HIGH, _WR HIGH, _RD HIGH, _CS HIGH
    memset(bank0, 0, sizeof bank0); //Reset shadow registers
    memset(bank1, 0, sizeof bank1);
}

void YM2612::Reset()
{
    digitalWriteFast(_IC, LOW);  //_IC HIGH
    delayMicroseconds(25);
    digitalWriteFast(_IC, HIGH); //_IC HIGH
    delayMicroseconds(25);
    memset(bank0, 0, sizeof bank0); //Reset shadow registers
    memset(bank1, 0, sizeof bank1);
}

void YM2612::DumpShadowRegisters()
{
  int line = 0x21;
  Serial.println("--------GLOBAL BANK--------");
  for(int i = 0; i < 0x30-0x21; i++)
  {
    if(i % 8 == 0)
    {
      if(i!=0)Serial.println();
      Serial.print("0x"); Serial.print(line, HEX); Serial.print(": ");
      line+=8;
    }
    if(bank0[i] < 16)
      Serial.print("0");
    Serial.print(bank0[i], HEX); Serial.print(" ");
  }
  Serial.println(); Serial.println();

  line = 0x30;
  Serial.println("--------BANK 0--------");
  for(int i = 0; i < 0xB7-0x30; i++)
  {
    if(i % 8 == 0)
    {
      Serial.println();
      Serial.print("0x"); Serial.print(line, HEX); Serial.print(": ");
      line+=8;
    }
    if(bank0[i+0x0F] < 16)
      Serial.print("0");
    Serial.print(bank0[i+0x0F], HEX); Serial.print(" ");
  }
  Serial.println(); Serial.println();

  line = 0x30;
  Serial.println("--------BANK 1--------");
  for(int i = 0; i < 0xB7-0x30; i++)
  {
    if(i % 8 == 0)
    {
      if(i!=0)Serial.println();
      Serial.print("0x"); Serial.print(line, HEX); Serial.print(": ");
      line+=8;
    }
    if(bank1[i] < 16)
      Serial.print("0");
    Serial.print(bank1[i], HEX); Serial.print(" ");
  }
}

void YM2612::send(unsigned char addr, unsigned char data, bool setA1)
{
    //Store in shadow registers to keep track of written values
    if(setA1)
    {
      bank1[addr-0x30] = data;
    }
    else
    {
      bank0[addr-0x21] = data;
    }
    
    digitalWriteFast(_A1, setA1);
    digitalWriteFast(_A0, LOW);
    digitalWriteFast(_CS, LOW);
    PORTF = addr;
    digitalWriteFast(_WR, LOW);
    delayMicroseconds(1);
    digitalWriteFast(_WR, HIGH);
    digitalWriteFast(_CS, HIGH);
    digitalWriteFast(_A0, HIGH);
    digitalWriteFast(_CS, LOW);
    PORTF = data;
    digitalWriteFast(_WR, LOW);
    delayMicroseconds(1);
    digitalWriteFast(_WR, HIGH);
    digitalWriteFast(_CS, HIGH);
    digitalWriteFast(_A0, LOW);
}

void YM2612::SetFrequency(uint16_t frequency, uint8_t channel)
{
  int block = 2;
  
  uint16_t frq;
  while(frequency >= 2048)
  {
    frequency /= 2;
    block++;
  }
  frq = (uint16_t)frequency;
  bool setA1 = channel > 2;

  // unsigned char f1 = ((frq >> 8) & mask(3)) | ((block & mask(3)) << 3);
  // unsigned char f2 = frq;
  // Serial.println("-------");
  // Serial.print("0xA4: "); Serial.println(f1, HEX);
  // Serial.print("0xA0: "); Serial.println(f2, HEX);
  // Serial.print("A1 SET: "); Serial.println(setA1 ? "TRUE" : "FALSE");
  // Serial.println(0xA4+channel%3, HEX);
  // Serial.println("-------");

  send(0xA4 + channel%3, ((frq >> 8) & mask(3)) | ((block & mask(3)) << 3), setA1);
  send(0xA0 + channel%3, frq, setA1);
}

float YM2612::NoteToFrequency(uint8_t note)
{
    //Elegant note/freq system by diegodorado
    //Check out his project at https://github.com/diegodorado/arduinoProjects/tree/master/ym2612
    const static float freq[12] = 
    {
      //You can create your own note frequencies here. C4#-C5. There should be twelve entries.
      //YM3438 datasheet note set
      277.2, 293.7, 311.1, 329.6, 349.2, 370.0, 392.0, 415.3, 440.0, 466.2, 493.9, 523.3

    }; 
    const static float multiplier[] = 
    {
      0.03125f,   0.0625f,   0.125f,   0.25f,   0.5f,   1.0f,   2.0f,   4.0f,   8.0f,   16.0f,   32.0f 
    }; 
    float f = freq[note%12];
    return (f+(f*TUNE))*multiplier[(note/12)+octaveShift];
}

uint8_t chIndex = 0;
void YM2612::SetChannelOn(uint8_t key, uint8_t velocity, bool velocityEnabled)
{
    uint8_t openChannel = 0xFF;
    for(int i = 0; i<MAX_CHANNELS_YM; i++)
    {
        if(!channels[i].keyOn || channels[i].keyNumber == key)
        {
            if(channels[i].keyNumber == key && channels[i].sustained)
            {
              //Turn off the sustained channel before turning it back on again
              uint8_t offset = i % 3;
              bool setA1 = i > 2;
              send(0x28, 0x00 + offset + (setA1 << 2));
            }
            channels[i].keyOn = true;
            channels[i].keyNumber = key;
            channels[i].blockNumber = key/12;
            channels[i].sustained = YMsustainEnabled;
            channels[i].index = chIndex;
            openChannel = i;
            break;
        }
    }
    uint8_t highestIndex = 0xFF;
    if(openChannel == 0xFF) //All channels full, kill the oldest note
    {
      for(int i = 0; i<MAX_CHANNELS_YM; i++)
      {
        if(channels[i].index < highestIndex)
          highestIndex = channels[i].index;
      }
      uint8_t offset = highestIndex % 3;
      bool setA1 = highestIndex > 2;
      send(0x28, 0x00 + offset + (setA1 << 2));
      channels[highestIndex].keyOn = true;
      channels[highestIndex].keyNumber = key;
      channels[highestIndex].blockNumber = key/12;
      channels[highestIndex].sustained = YMsustainEnabled;
      channels[highestIndex].index = chIndex;
      openChannel = highestIndex;
    }
    chIndex++;
    chIndex %= MAX_CHANNELS_YM;

    uint8_t offset = openChannel % 3;
    bool setA1 = openChannel > 2;
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

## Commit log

2019-01-10 opm file requests and fixed out-of-bounds opm voice selections
    [main.cpp]
2019-01-10 Added hardware voice swap buttons
    [main.cpp]
2019-01-10 Fixed voice 0 load bug
    [main.cpp]
2019-01-10 fixed patch program swapping
    [main.cpp]
2019-01-12 New frequency system and pitch bending
2019-01-15 Added LFO toggle button
2019-01-16 Removed LTC6903, replaced with 8MHz crystal. Tuned instrument for 8MHz
    [main.cpp]
2019-01-18 Tuned PSG, LFO only responds to control command 0x01 (mod wheel)
2019-01-18 YM2612 driver refactor
2019-01-19 Fixed broken operator registers
    [YM2612.cpp, main.cpp]
2019-01-19 Moved octave shifting for YM to YM driver
2019-01-20 Fixed LFO register reset
    [YM2612.cpp]
2019-01-25 Fixed pitch bend issue for YM
    [YM2612.cpp]
2019-02-02 Added basic rotary encoder support
2019-02-25 schematic rough complete
2019-03-06 Changes for PCB Version
2019-03-07 Added SD failure mode
    [main.cpp]
2019-03-08 LCD shows favorites & fixed YM pitchbend
    [YM2612.cpp, main.cpp]
2019-03-08 Fixed unresponsive favorite 7 button
    [main.cpp]
2019-03-08 Removed old debug printout
2019-04-10 Starting fix on PSG noise channel
    [SN76489.cpp, SN76489.h, YM2612.cpp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]
2019-04-14 Fixed opm parser bug
    [main.cpp]
2019-04-17 Fixed upper bank voice bug and added YM shadow registers + readout
    [YM2612.cpp, main.cpp]
2019-04-23 Adjusted USB device name
2019-04-23 Added schematic files
    [YM2612_MIDI_SMD-B.Cu.gbr, YM2612_MIDI_SMD-B.Mask.gbr, YM2612_MIDI_SMD-B.Paste.gbr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]
2019-04-23 Added schematic libs
2019-04-26 Added footprint cache
2019-04-28 Added tool EXEs and fixed serial
    [main.cpp]
2019-04-28 Added center-positive logo to FSS
    [YM2612_MIDI_SMD-B.Cu.gbr, YM2612_MIDI_SMD-B.Mask.gbr, YM2612_MIDI_SMD-B.Paste.gbr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]
2019-04-30 Added YM key velocity setting on MIDI CHANNEL 3
2019-04-30 YM and PSG now both have optional velocity. Added ArduinoISP scripts and tools
2019-05-03 Velocity is iffy on a 6-voice synth. No velocity now made default MIDI CH 1-2
2019-05-06 Updated flasher script with teensy dir wildcard
2019-05-16 Fixed minor bug on favorite button #7
    [YM2612_MIDI_SMD-B.Cu.gbr, YM2612_MIDI_SMD-B.Mask.gbr, YM2612_MIDI_SMD-B.Paste.gbr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]
2019-05-20 Move cursor off of file browser line to prevent LCD from updating, causing noise
    [main.cpp]
2019-06-01 Moved LCD redraw out of rotary encoder interrupt
2019-06-14 LC filter value correction
    [YM2612_MIDI_SMD.sch]
2019-06-23 Begin hardware revision. New amp
    [YM2612_MIDI_SMD.sch]
2019-06-29 New power delivery
    [YM2612_MIDI_SMD.sch]
2019-06-30 Analog stage
    [YM2612_MIDI_SMD.kicad_pcb, YM2612_MIDI_SMD.sch]
2019-06-30 Route complete
    [YM2612_MIDI_SMD.kicad_pcb, YM2612_MIDI_SMD.sch]
2019-06-30 Silk screen
    [YM2612_MIDI_SMD.kicad_pcb]
2019-07-01 PCB Complete
    [YM2612_MIDI_SMD-B.Cu.gbr, YM2612_MIDI_SMD-B.Mask.gbr, YM2612_MIDI_SMD-B.Paste.gbr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]
2019-07-05 Amend PSG resistors
    [YM2612_MIDI_SMD.sch]
2019-07-05 Adjusted resistor values
    [YM2612_MIDI_SMD.sch]
2019-07-10 New boost circuit
    [YM2612_MIDI_SMD.kicad_pcb, YM2612_MIDI_SMD.sch]
2019-07-16 Amplifier notations
    [YM2612_MIDI_SMD.sch]
2019-07-28 PSG Noise support on MIDI CH. 5
    [YM2612_MIDI_SMD-B.Cu.gbr, YM2612_MIDI_SMD-B.Mask.gbr, YM2612_MIDI_SMD-B.Paste.gbr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]
2019-09-11 framework laid out. Needs to be verified and cleaned
2019-09-16 Added flasher usb drivers
2019-09-21 Per-slot patch setting. Fixed key-off algo for individual slots
    [YM2612.cpp, main.cpp]
2021-02-16 Operator order fix
    [MM_BOM_JAN_17_2021.xlsx, Mega_MIDI_Bottom_Plate.3mf, Mega_MIDI_Bottom_Plate.stl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]
2021-05-27 Filename scrolling reset fix
    [main.cpp]
2021-05-27 fix: couldn't access last (64th) voice in opm file
    [main.cpp]
2021-11-09 Update README.md
    https://forum.kicad.info/t/warning-avoid-all-links-to-kicad-pcb-org-use-kicad-org/31521
2022-04-03 Encoder invert option
    [YM2612_MIDI_SMD-NPTH.drl, YM2612_MIDI_SMD.drl]

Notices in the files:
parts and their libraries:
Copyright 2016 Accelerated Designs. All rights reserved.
